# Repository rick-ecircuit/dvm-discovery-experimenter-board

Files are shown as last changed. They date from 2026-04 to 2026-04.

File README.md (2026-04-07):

# DVM Discovery Board
## Intro
The DVM Discovery Board allows students, engineers and DIYers to quickly build and learn key voltage measuring concepts and circuits. Hands-on prototyping and experimenting boosts understanding and intuition!

dvm pcb, sch

* Easy-to-use Experimenter Board.
* Circuit Options
	* 1 to 3 Customizable Voltage Ranges
	* Unipolar (+ input only) or Bipolar (+ / - input)
	* Precision Mode (Vref option)
	* Range Select: Manual Push-button or Auto 
* Simple interface to the Arduino UNO (or other MicroController).
* C Code Examples - run, modify, expand!
* Excel Design Calculator - gains, RC values, resolution, settling time.

## Flexible Hands-On Learning
* Quickly build and explore multiple measurement options. 
* Solderless headers for easy component changes.

## Building Blocks
Start with the basic circuit blocks
* Input Divider (2 Ranges)
* Low-Pass Filter
* Push-Button
Block diagram

Add blocks to expand your project
* Amplifier (additional range)
* Negative Rail (bipolar input)
* Voltage Reference (precision mode).

## Micro-Controller & C Code
* Easily interfaces to a MicroController Bd like the Arduino UNO.
* Run the code for the Basic or Advanced Voltmeter. Modify or customize for your project.
	* Basic ( 2-Range, Unipolar Input ):  DVM_discovery_basic_1.ino
	* Advanced ( 3-Range, Bipolar Input ):  DVM_discovery_3range_bipolar_1.ino

## User's Guide
* Description, Schematics, BOM
* Design and analysis equations
* DVM Examples: Basic and Advanced

## KiCAD Files
The schematic and PCB were created with KiCad, a free and open-source software suite that provides a complete EDA toolset including schematic capture, PCB layout, 3D visualization. https://www.kicad.org/

## Open-Source Project
The DVM Discovery is Open Source - anyone can inspect, make, modify and distribute the project.
Download PDFs and KiCAD PCB files (schematic, PCB, etc.).

## Excel Op Amp Design Calculator
An Excel Toolkit of Calculations created for hands-on experimenting. Apply, modify or customize as needed!
* Input Divider & Amplifier 
* Low-Pass Filter 
* Scale & Shift Network
* ADC Conversion and Resolution

<br>Let me know what you find helpful or any other comments and suggestions. Thanks!  
www.ecircuitcenter.com/contact.htm

Have fun on your next learning / design / coding adventure!

Rick  
eCircuit Center  
https://ecircuitcenter.com/

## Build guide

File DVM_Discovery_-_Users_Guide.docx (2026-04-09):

# DVM Discovery

# Hands-On & Flexible Learning of Digital Voltmeter Circuits

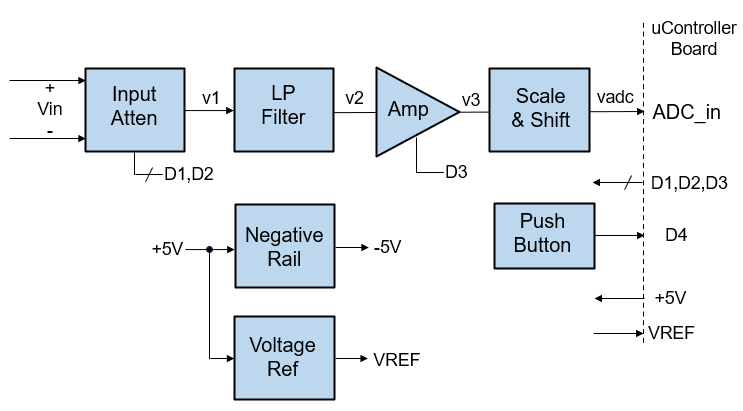
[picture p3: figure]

Contents

# 1 Intro

The DVM Discovery Board allows students, engineers and DIYers to quickly build and experiment with a variety of Digital Voltmeter Circuits. Hands-on learning of real-world circuits boosts understanding and intuition!

- Easy-to-use experimenter board
- Solderless headers allow quick component changes
- Multiple circuit design options
  - 1 to 3 Customizable Voltage Ranges
  - Unipolar (+ input only) or Bipolar (+/- input)
  - Range Select: Manual or Auto
  - Precision Mode (voltage reference option)
- Simple Interface to uController Boards (ex: Arduino UNO)
- Excel Toolkit calculates component values, ranges and resolution.

# 2 Overview

The DVM Discovery provides flexible circuitry for a multi-range voltmeter and easy uController interface. You can quickly build and explore many measurement options.

YELLOW boxes show solderless headers for easy component changes!

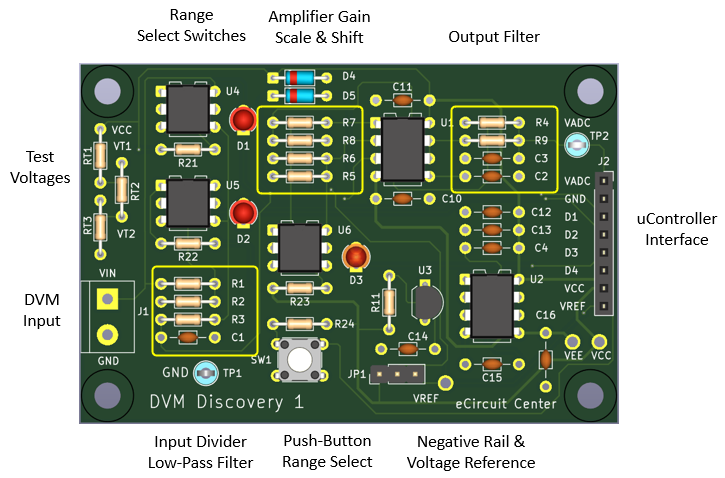
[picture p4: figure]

- Input Divider: Standard & High-Voltage Range option
- Amplifier: Low-Voltage Range option
- Negative Rail: Bipolar Input option
- Voltage Reference: Precision Mode option
- Push-Button Range Select
- LED Indicators - Digital Output Level

# 3 Applications

Here’s just a few of the real-world measurements needed across the ranges,

- 1V Range - diodes, pressure / temperature sensors, current sense voltages.
- 5V Range - 1.5V household batteries, 3.3V / 5V supplies, 4V power-tool batteries.
- 25V Range - 9V household / 12V auto batteries, 15V supplies, 18V solar cell

NOTE: You can customize the 1V / 25V ranges for your application (48V eBike batteries for example). See Make It! Section.

# 4 Block Diagram

The basic blocks allow for flexible build / design options. Customize for functionality as well as your learning goals.

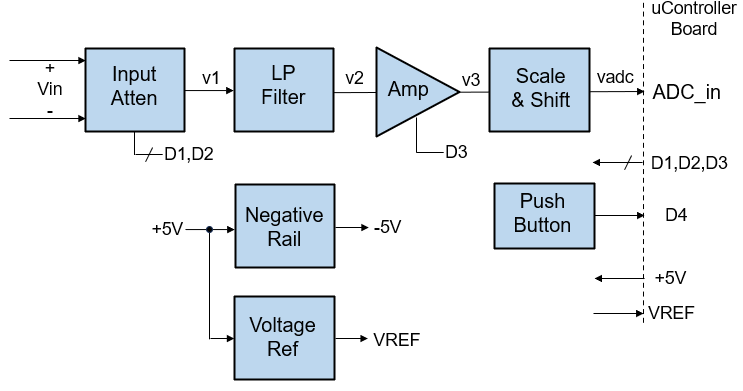
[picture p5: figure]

# 5 Simplified Signal Flow

The simplified diagram below shows the main path of the measured signal.

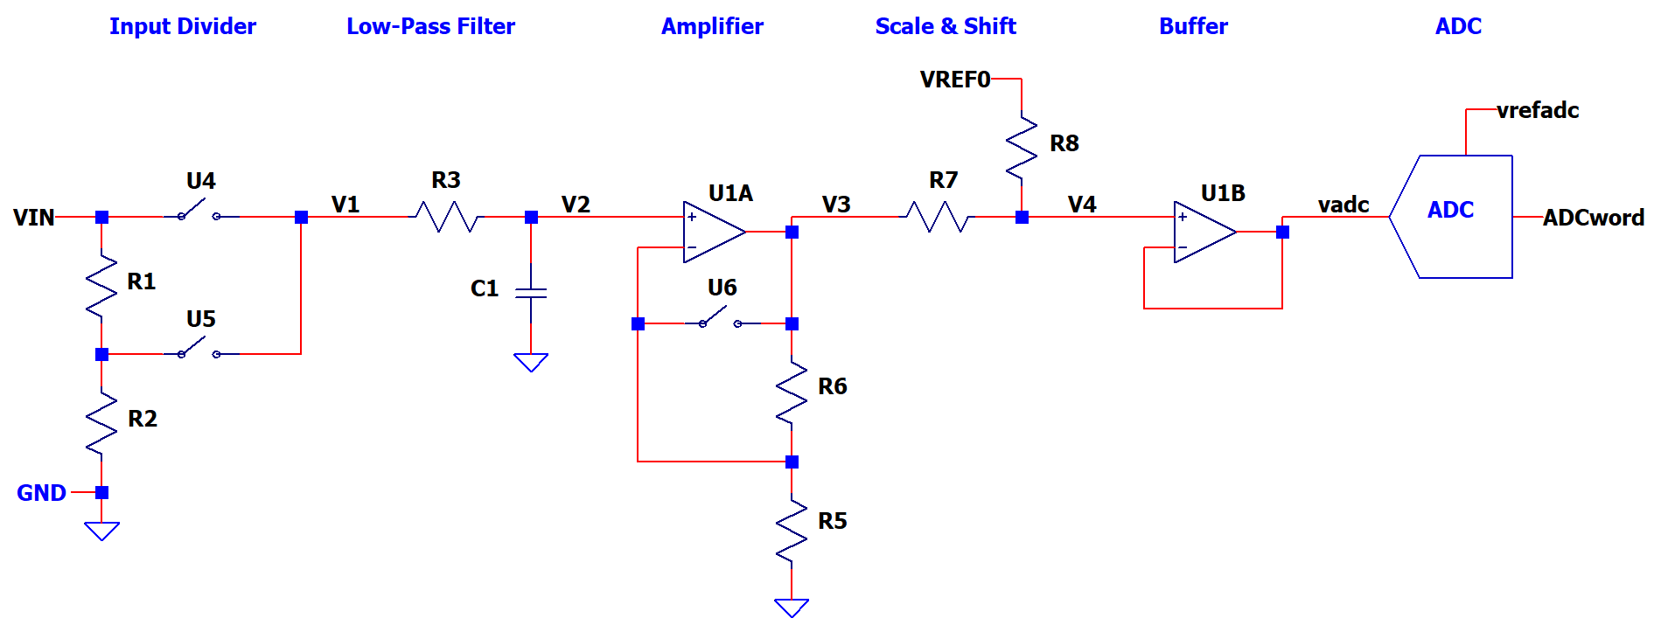
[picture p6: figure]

# 6 Gain Stages vs Ranges

How can you achieve three voltage ranges? The RED shading shows CLOSED switches.

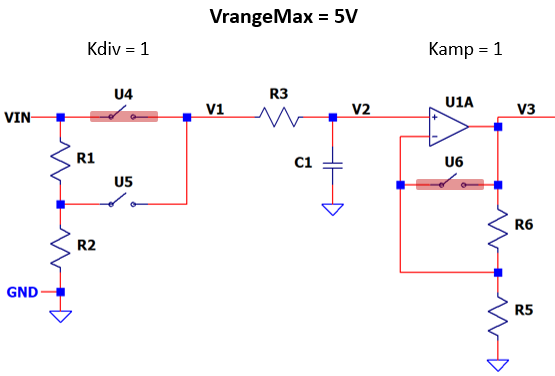
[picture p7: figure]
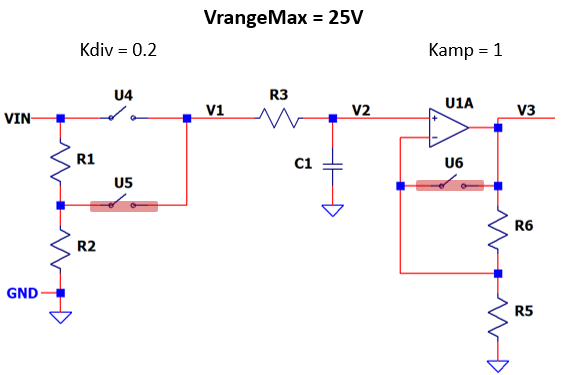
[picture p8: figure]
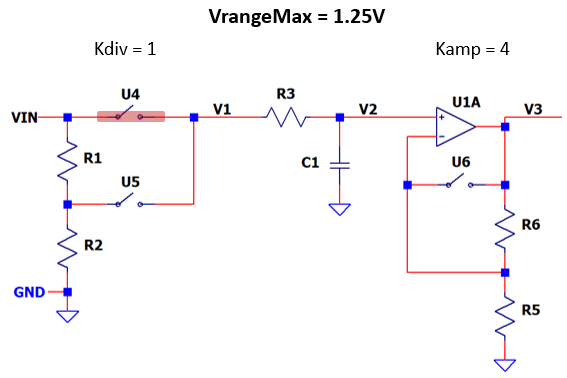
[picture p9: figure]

# 7 Schematic

The DVM Discovery is created using straightforward circuits and standard parts. They provide practical real-world applications of classic circuits. You can also deep dive into the theory of these foundational circuits as well.

NOTE: For full schematic, see Bonus Sections.

## 7.1 Input Divider, Analog Mux, Low-Pass Filter

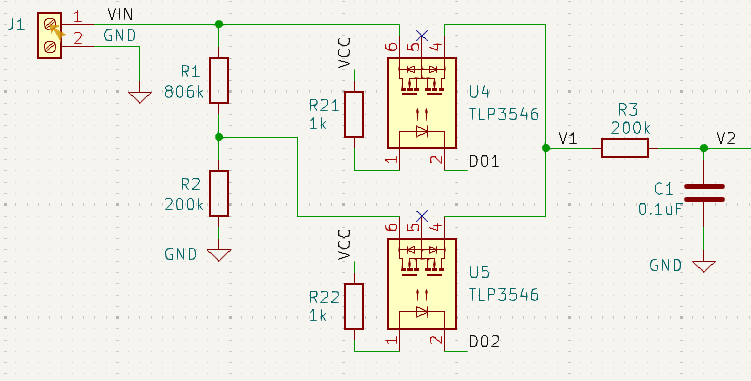
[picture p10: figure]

Input Voltage Divider

- The R1, R2 Divider scales down high voltages to the +5V max of the ADC input. Kdiv = V1 / Vin = R2 / (R1+R2)

Analog Mux

- Solid-State Relays U4 and U5 create an Analog Mux
  - Normal Voltage Range: U4 connects Vin directly to V1.
  - High Voltage Range: U5 connects the Divider tap to V1.

Low-Pass Filter

- R3, C1 create a low-pass filter: fc = 1 / (2 * pi* R3 * C1)
- Reduces unwanted 60Hz, radio interference and protects against input spikes.

## 7.2 Amplifier with Selectable Gain

You can configure U1 as a selectable gain amplifier or a unity-gain buffer.

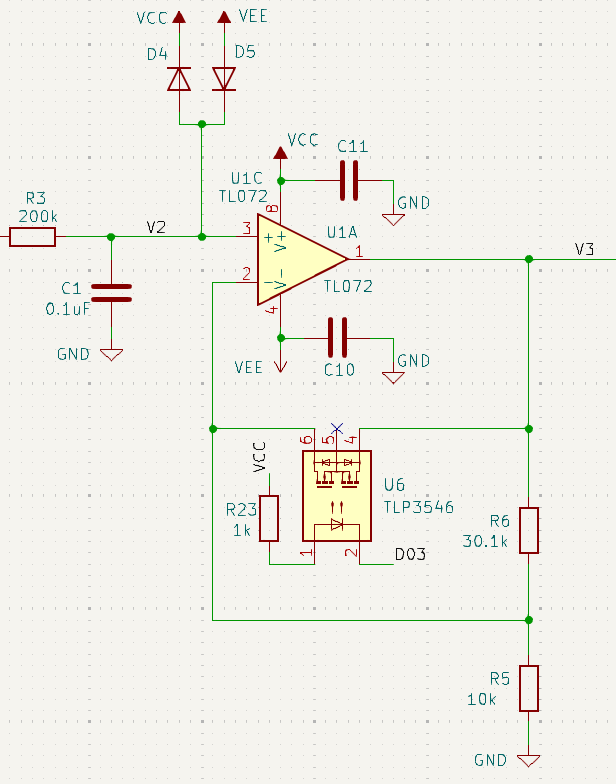
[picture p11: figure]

Selectable Gain Amplifier

- Unity Gain Amplifier - U6 Switch ON
  - U6 shorts U1 output to negative input.
- Gain Amplifier - U6 Switch OFF
  - Ka = V3 / V2 = R6 / R5 + 1

Unity-Gain Amplifier

- U6 not used.
- R5 = short (or < 100 ohms)
- R6 = open

Input Protection

- Schottky Diodes D4, D5 limit V2 to within VCC and VEE keeping U1’s pins under their MAX voltage input rating.

## 7.3 Scale & Shift, Buffer

You can scale and shift a bipolar input (-5V to 5V) to a unipolar one (0V to 5V) using a simple two resistor network R7, R8!

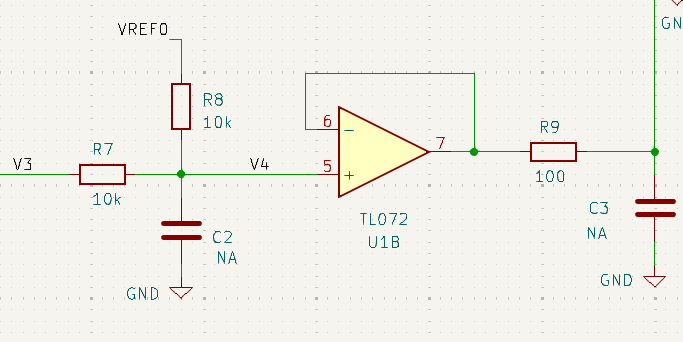
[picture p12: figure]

Scale and Shift

Kscale=(V4)/(V3)=(R8)/(R7+R8)

Voffset=VREF0∙(R7)/(R7+R8)

Unipolar Input Mode – No Scale or Shift

- Input: V3 = 0 to 5V Range
- Output: V4 = 0 to 5V Range
  - R7 = 1k, R8 = open
  - Scale: Kscale = 1 (Unity Gain)
  - Shift: Voffset = 0V

Bipolar Input Mode - Scale & Shift

- Input: V3 = -5V to 5V Range
- Output: V4 = 0 to +5V Range
  - R7 = 10k, R8 = 10k, VREF0 = +5.0V
  - Scale: Kscale = R8 / (R7+R8) = 0.5
  - Shift: Voffset = Vref0 * R7 / (R7+R8) = +2.5V
  - V4 = V3*0.5 + 2.5V

Optional Low-Pass Filters

- R7||R8 and C2: fc = 1 / (2 * π * R7||R8 * C2)
- R9 and C3: fc = 1 / (2 * π * R10 * C3)

## 7.4 Buffer and External Interface

Output Buffer

- U1B buffers the medium impedance at node V4 and drives the Microcontroller’s ADC input.
- R9 can provide isolation from capacitive load if driving long cables / wires to ADC input.
- C3 (and R9) can provide addition low-pass filtering.

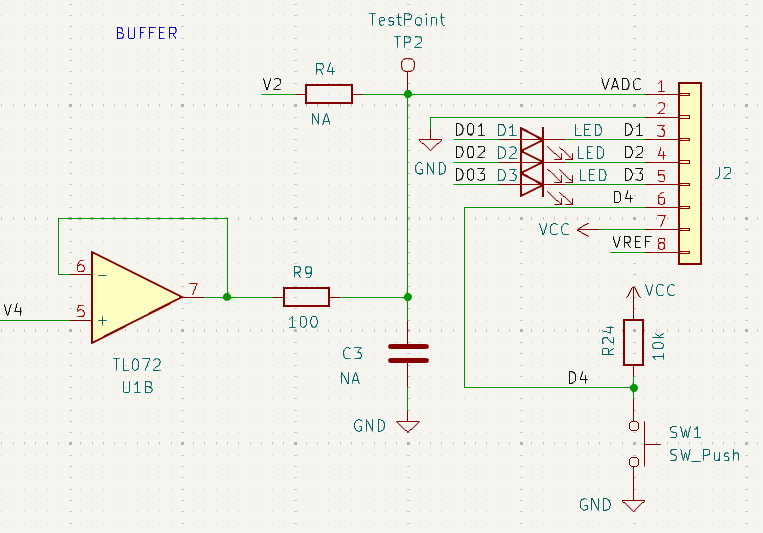
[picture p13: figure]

Microcontroller Interface

- Connector J2 allows easy access to external controller or computer.

Signals | Controller Signal | Description
VCC, GND | Power | Power for DVM PCB
D1, D2, D3 | Digital Outputs | Solid-State Switch Control Low State – Turns ON U4, U5, U6
D4 | Digital Input | Push-Button State for Range Select.
ADC | Analog Input A0 | Voltmeter Reading
VREF | Analog Input (A1) | Reference Voltage for Precision Mode

Pushbutton

- SW1 for external input to manually select Vrange.

LED Indicators - Digital LO & Switch ON

- LEDs (D1,D2,D3) light up when digital outputs (D1,D2,D3) are driven LO turning Opto-Switches (U4,U5,U6) ON.

## 7.5 Negative Rail

You’ll need a negative supply to power U1 for bipolar inputs.

- U2 is a Switched-Capacitor Converter that creates a negative voltage (VEE) from a positive input voltage (VCC).
- U2’s internal switches alternatively charge C15 to VCC then deliver the charge to C16.

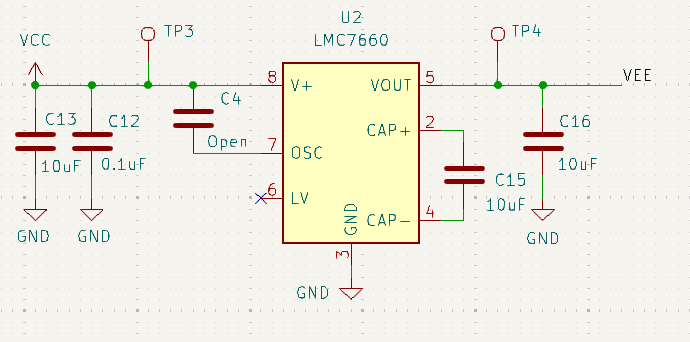
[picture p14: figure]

## 7.6 Voltage Reference

A precise voltage reference enables you to measure in Precision Mode.

- U7 is an IC that behaves like a precision 2-terminal Zener Diode.

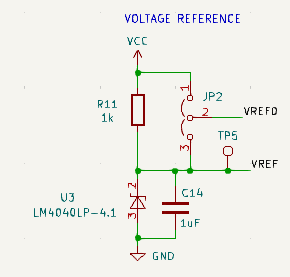
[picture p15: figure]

- VREF0 drives the Scale and Shift Network
  - VREF0 = VCC = +5V (JP1: 1-2)
  - VREF0 = VREF = +4.096V (JP1: 2-3)

Precision Mode Options

1. Connect VREF to an ADC input. You can measure this precision voltage and apply a Gain correction to all VIN readings.
2. Connect VREF directly to the Vref pin of the controller’s ADC. The ADC automatically scales the measurements to this reference.

## 7.7 Input Test Levels

A simple resistor string provides 3 handy on-board voltages for testing multiple ranges. For RT1 = RT2 = 10k and RT3 = 1k you get the following levels.

- VCC = +5V Supply.
- VT1 = VCC * (RT2+RT3) / (RT1+RT2+RT3) = 2.619V
- VT2 = VCC * (RT3) / (RT1+RT2+RT3) = 0.238V

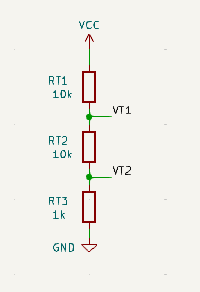
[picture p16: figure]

Create any two test voltages that you might need!

# 8 Voltage Range Setup

## 8.1 Ranges (Default)

Range | Vrange | Vrange Max | Overrange (%)
Standard | 4V | 5V | 25%
High | 20V | 25V | 25%
Low | 1V | 1.25V | 25%

## 8.2 Voltage Range, Gains and Digital Outputs

Voltage Range | Divider Gain | Amplifier Gain | Analog Switches | Digital Outputs
Standard | 1.0 | 1.0 | U4 = ON U6 = ON | D1 = LO D3 = LO
High | R2 / (R1+R2) | 1.0 | U5 = ON U6 = ON | D2 = LO D3 = LO
Low | 1.0 | R6 / R5 + 1 | U4 = ON | D1 = LO

NOTE: LED’s D1, D2, D3 turn ON when digital outputs D1, D2, D3 go LO!

## 8.3 Signal Levels

Polarity | VIN | V4 | VADC
Unipolar | 0V to +Vrange_max | 0V to +5V | 0V to +5V 0V at VIN = 0
Bipolar | -Vrange_max to +Vrange_max | -5V to +5V | 0V to +5V 2.5V at VIN = 0

## 8.4 Software Calculation of VIN

Polarity | VIN | Ktot | Calc VIN from ADCword
Unipolar | 0 to +Vrange_max | Kdiv*Kamp | VIN = (ADCword / 1024 * VREF) / Ktot
Bipolar | -Vrange_min to +Vrange_max | Kdiv*Kamp*Kscale | VIN = (ADCword / 1024 * VREF – VREF / 2) / Ktot

# 9 DVM Basic - 2 Ranges, Unipolar Input

Let’s take our DVM for a test drive! Build this voltmeter to get some hands-on experience with multi-ranges. You’ll get to apply some real-world testing of your house-hold batteries.

Description

- Ranges: +4V, +20V
- Input: Unipolar (Pos input only)
- Range Select: Manual Push-Button
- Low-Pass Filter: 8 Hz
- Overrange: +5V, +25V (25%)

Simplified Schematic

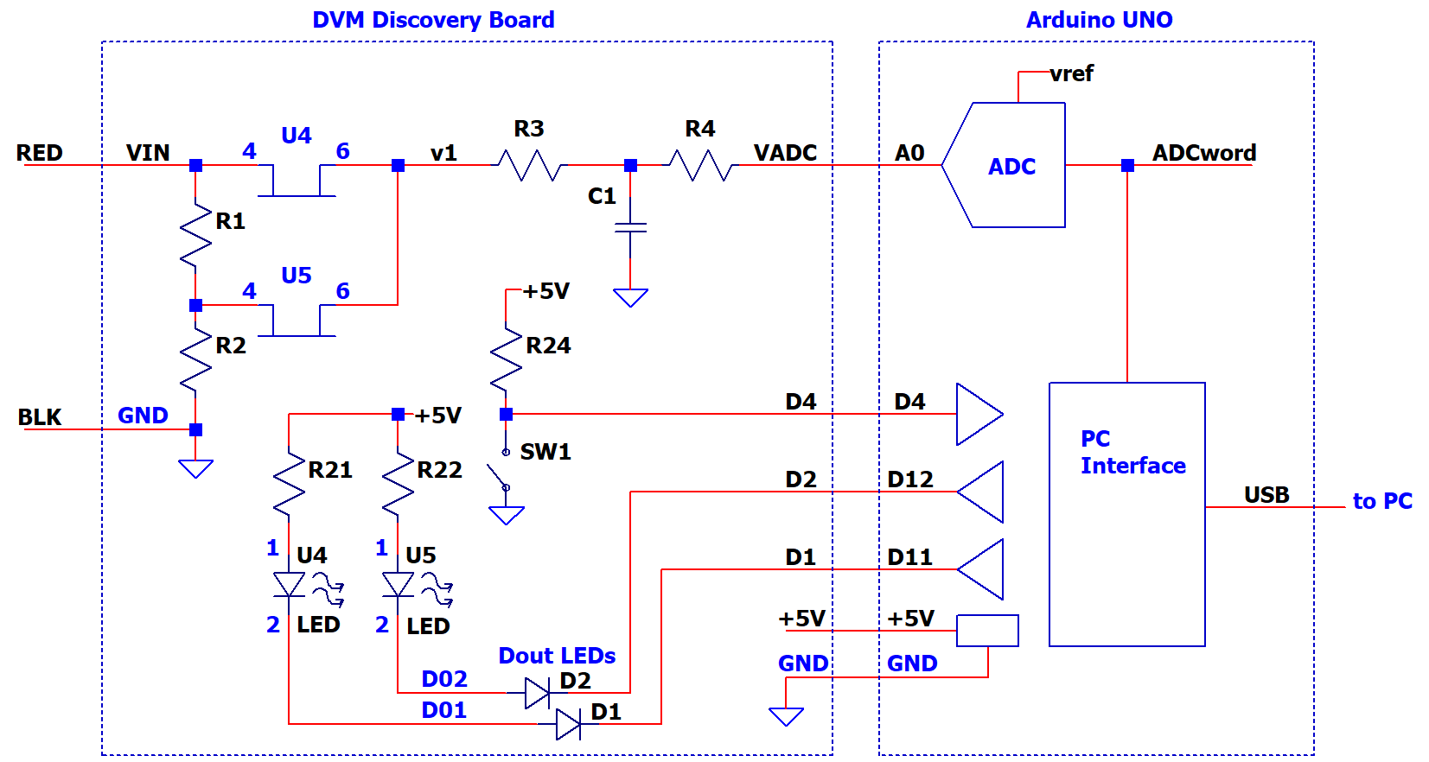
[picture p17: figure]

Install Components on PCB (See DVM Basic in Make it! Section)

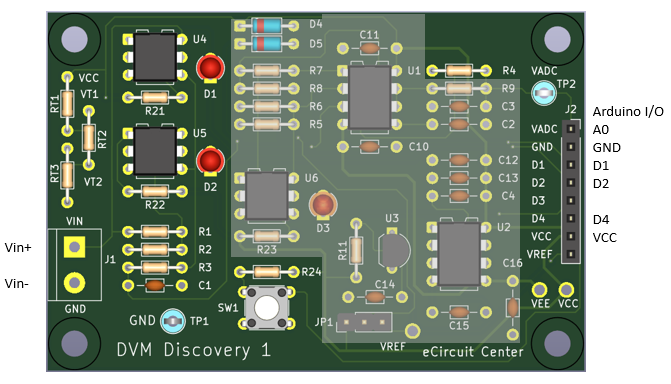
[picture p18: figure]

Install Components on 4-Pin Solderless Headers

- R1 = 825k, R2 = 200k (Input Divider)
- R3 = 200k, C1 = 0.1uF (Low-Pass Filter)
- R4 = 1k (connect to VADC)

Option: Solder components above directly on PCB without headers.

Connect Arduino UNO to DVM Discovery

Arduino | Description | Discovery | Description
A0 | Analog ADC Input | VADC | Measured Voltage Signal
D11, D12 | Digital Outputs | D1, D2 | Opto-Switch Control and LEDs
D4 | Digital Input | D4 | Push-Button Logic State
+5V, GND | Power | VCC, GND | Power for Switches, Amp, etc.

Check Out

- Connect Arduino USB to PC or Laptop
- Use a DVM to verify +5.0V between Testpoints VCC and GND.

Run Code

- Download the file: DVM_discovery_basic_1.ino
- Start the Arduino IDE and Open the file listed above.
- Hit the Upload and Run buttons.
- Press pushbutton repeatedly and verify that LEDs D1 and D2 alternately turn ON and OFF.

Test Voltage

- Press the push-button to select the 4V Range. LEDs: D1 = ON, D2 = OFF
- Connect the VIN Test Clip (RED) to VT1 (2.69V).
- Read voltage at Arduino Serial Monitor on the PC screen.
- Very the reading is within +/-0.05V
- Press the push button to select the 20V Range. LEDs: D1 = OFF, D2 = ON
- Read voltage.
- Very the reading is within +/-0.1V

Test 1.5V and 9V Batteries

- Connect a 1.5V or 9V battery’s + and -leads to VIN and GND.
- Select the 4V or 20V Range.
- Check 1.5V health - between 1.1V and 1.5V
- Check 9V health - between 7.5V and 9V.

# 10 DVM Advanced - 3 Ranges, Bipolar Input

Let’s extend the capabilities of our DVM to 3 Voltage Ranges and measure both
+/- input polarities!

Description

- Ranges: ±1V, ±4V, ±20V
- Input: Bipolar (Pos & Neg Voltages)
- Range Select: Manual Push-Button
- Low-Pass Filter: 8 Hz
- Overrange: ±1.25V, ±5V, ±25V (25%)

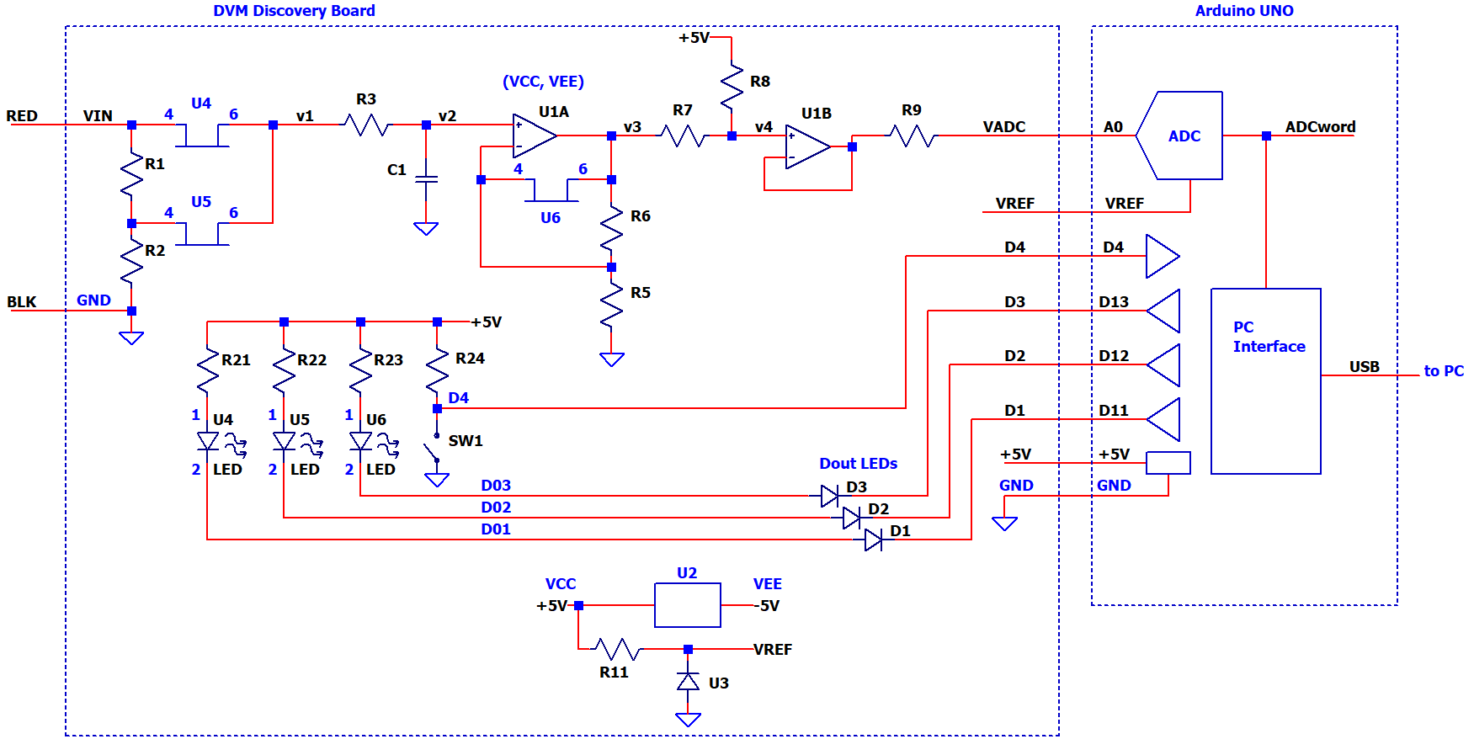
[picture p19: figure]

Simplified Schematic

Install Components on PCB (See DVM Advanced in Make it! Section)

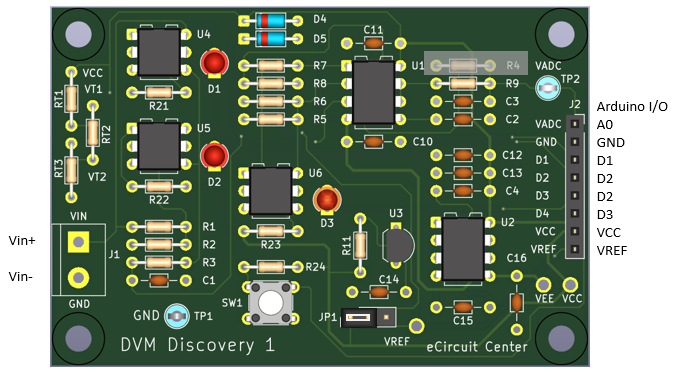
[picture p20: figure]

Install Components on 4-Pin Solderless Headers

- R1 = 825k, R2 = 200k (Input Divider)
- R3 = 200k, C1 = 0.1uF (Low-Pass Filter)
- R5 = 10k, R6 = 30.1k (Amplifier)
- R7 = 10k, R8 = 10k (Scale and Shift)
- R9 = 1k (connect to VADC)

Option: Solder components above directly on PCB without headers!

Jumpers

- JP1:1-2 (VREF0 = +5V)

Connect Arduino UNO to DVM Discovery

Arduino | Description | Discovery | Description
A0 | Analog ADC Input | VADC | Measured Voltage Signal
D11, D12, D13 | Digital Outputs | D1, D2, D3 | Opto-Switch Control and LEDs
D4 | Digital Input | D4 | Push-Button Logic State
+5V, GND | Power | VCC, GND | Power for Switches, Amp, etc.

Check Out

- Connect Arduino USB to PC or Laptop
- Use a DVM to verify +5.0V between Testpoints VCC and GND.
- Verify -5.0V between VEE and GND.
- Verify +4.906V between VREF and GND.

Run Code

- Download the file: DVM_discovery_3range_bipolar_1.ino
- Start the Arduino IDE and Open the file listed above.
- Hit the Upload and Run button.
- Press pushbutton repeatedly and verify that LEDs D1, D2, D2 turn ON and OFF.

4V Range

- Press the push-button to select the 4V Range. LEDs: D1 = ON, D2 = OFF, D3 = ON
- Connect the VIN Test Clip (RED) to VT1 (2.619V).
- Read voltage at Arduino Serial Monitor on the PC screen.
- Verify the reading is within +/-0.05V

20V Range

- Press the push button to select the 20V Range. LEDs: D1 = OFF, D2 = ON, D3 = ON
- Connect the VIN Test Clip (RED) to VT1 (2.619V).
- Verify the reading is within +/-0.1V

1V Range

- Press the push button to select the 1V Range. LEDs: D1 = ON, D2 = OFF, D3 = OFF
- Connect the VIN Test Clip (RED) to VT2 (0.238V).
- Verify the reading is within +/-0.05V

# 11 Make it!

Here’s the parts list for the Basic and Advanced DVMs.

- Modify and build for your own learning goals.
- Install only parts needed for your design.
- All Resistors: 1/4W, 5% unless noted.
- All Capacitors: Ceramic, >25V

You can customize the high and low ranges for your application.

- High Range (25V default) – adjust R1, R2
- Low Range (1V default) – adjust R6, R5

## 11.1 DVM Basic - 2 Ranges, Unipolar Input

PASSIVES

R1 | 1 | 825k | 1% for precision | Install group on 4-pin headers
R2 | 1 | 200k | 1% for precision
R3 | 1 | 200k
C1 | 1 | 0.1uF
R4 | 1 | 1k | | Install group on 4-pin headers
R9 | 1 | Open
C3 | 1 | Open | | Optional low-pass filtering
C2 | 1 | Open | | Optional low-pass filtering
R21, R22 | 2 | 1k
RT1, RT2 | 2 | 10k
RT3 | 1 | 1k
D4, D5 | 2 | Diode | 1N5711
D1, D2 | 2 | LED Yel | LTL-4253 | Any color you prefer.

INTEGRATED CIRCUITS

U4, U5 | 2 | Opto-Isolated Solid-State Switch | TLP592 type or equivalent | Ron < 10 ohms

HARDWARE

R1 - C1 R4 - C3 | 4 | 4-pin Socket Header for components | SSW-104-01-T-S | Install on both sides of component groups.
U4, U5 | 4 | 3-pin female break-away socket strip | | Install on both sides for opto switches.
J2 | 1 | 8-pin Socket Header | SSW-108-01-T-S
J1 | 1 | 2-pin Terminal Block screw type | | Optional: Solder test leads (spring or alligator clips) directly to J1 pads.
TP1 | 1 | TestPoint | 5011

## 11.2 DVM Advanced - 3 Ranges, Bipolar Input

PASSIVES

C10, C11, C12 | 3 | 0.1uF | | All caps Ceramic, >25V
C13, C14, C15, C16 | 2 | 10uF
R1 | 1 | 825k | 1% for precision | Install group on 4-pin headers
R2 | 1 | 200k | 1% for precision
R3 | 1 | 200k
C1 | 1 | 0.1uF
R5 | 1 | 10k | 1% for precision | Install group on 4-pin headers
R6 | 1 | 30.1k | 1% for precision
R7 | 1 | 10k | 1% for precision
R8 | 1 | 10k | 1% for precision
R4 | 1 | Open | | Install group on 4-pin headers
R9 | 1 | 1k
C3 | 1 | Open | | Optional low-pass filtering
C2 | 1 | Open | | Optional low-pass filtering
R11, R21, R22, R23 | 4 | 1k
RT1, RT2 | 2 | 10k
RT3 | 1 | 1k
D4, D5 | 3 | Diode | 1N5711
D1, D2, D3 | 3 | LED Yel | LTL-4253 | Any color you prefer.

INTEGRATED CIRCUITS

U1 | 1 | Op Amp | LMC6082IN/NOP8 | Dual op amp, rail-to-rail output, +/-7.5V supply max, DIP
U2 | 1 | Negative Rail Charge Pump | AD7660NP
U3 | 1 | Voltage Reference Shunt | LM4040xx
U4, U5, U6 | 3 | Opto-Isolated Solid-State Switch | TLP592 type or equivalent | Ron < 10 ohms

HARDWARE

R1 - C1 R5 - R8 R4 - C3 | 6 | 4-pin Socket Header for components | SSW-104-01-T-S | Install on both sides of component groups.
U1, U2 | 2 | DIP-8 Socket | 4808-3000-CP
U4, U5, U6 | 6 | 3-pin female break-away socket strip | | Install both sides for opto switches.
J2 | 1 | 8-pin Socket Header | SSW-108-01-T-S
J1 | 1 | 2-pin Terminal Block screw type | | Optional: Solder test leads (spring or alligator clips) directly to J1 pads.
JP1 | 1 | 3-pin Header | TSW-103-08-T-S | 1 Shunts needed SNT-100-BK-T
TP1 | 1 | TestPoint | 5011

# 12 Bonus Sections

## 12.1 Revision & Notes

DVM Discovery User’s Guide: Rev 1a

The DVM Discovery provides real-world hands-on experiences to developing skills, understanding and intuition about measurement topologies.

Rick Faehnrich

https://www.linkedin.com/in/rick-faehnrich-2671a911/

## 12.2 Learning Styles

Dive in any way that propels your learning with Self-Directed or Guided Learning (or a combination of both).

- Self-Directed Learning - Explore circuits entirely on your own.
- Guided Examples – Follow a walk-through of two DVM implementations:
  - 2-Range, Unipolar Input
  - 3 Range, Bipolar Input
- Mixed Mode - Get ideas from the Guided examples and follow-through on your own.

## 12.3 Arduino Software

Here's the fast track steps of running a C program (sketch) on your Arduino Board.

- Download and install the Arduino IDE Software. https://www.arduino.cc/en/software
- Connect UNO Board to your computer https://docs.arduino.cc/hardware/uno-rev3/
- Open the Arduino IDE Software.
- Select Board Name Select UNO from drop down menu.
- Copy the program (sketch) to your Arduino folder and Open it. DVM_discovery_basic_1.ino
- Click Compile Button Generates executable code, checks for errors.
- Click the Upload Button Uploads compiled code into UNO and begins running.
- Click the Serial Monitor Window displays output from PrintSerial statement.

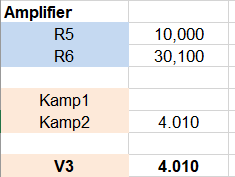
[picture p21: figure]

## 12.4 Excel DVM Design Calculator

A handy Design and Analysis Toolkit.
https://ecircuitcenter.com/DVM1/dvm-discovery.html

1. Calculate gains, signal levels and ADC digital values.
2. Modify, customize for your own projects.

## 12.5 KiCAD Software

KiCad is a free and open-source software suite that provides a complete EDA toolset including schematic capture, PCB layout, 3D visualization, and circuit simulation. https://www.kicad.org/

## 12.6 GitHub

The DVM Discovery Bd is an open-source project intended to make op amp learning as accessible and affordable as possible. You can download the documentation and KiCAD project files at https://github.com/rick-ecircuit.

## 12.7 Feedback eCircuitCenter

Feedback on eCircuit Center

- How is the DVM Discovery Bd helpful for you?
- What needs clarity?
- Other comments, suggestions?

Send your thoughts on the feedback form at eCircuit Center.
https://ecircuitcenter.com/contact.htm

eCircuit Center strives to provide informal, hands-on and fun experiences that lead to a deeper, more intuitive understanding of circuit design and analysis.

## 12.8 The Power of Play

- Key to analog success: play, play, play with circuits!
- Analog circuits appear more inviting (and less intimidating) when playing and tinkering.
- Learning and passion grow when you
  - Ask “what if” questions
  - Play with component values - Predict the outcome!
  - Small discoveries and learning fuel motivation and the joy of learning.

## 12.9 KiCAD Schematic

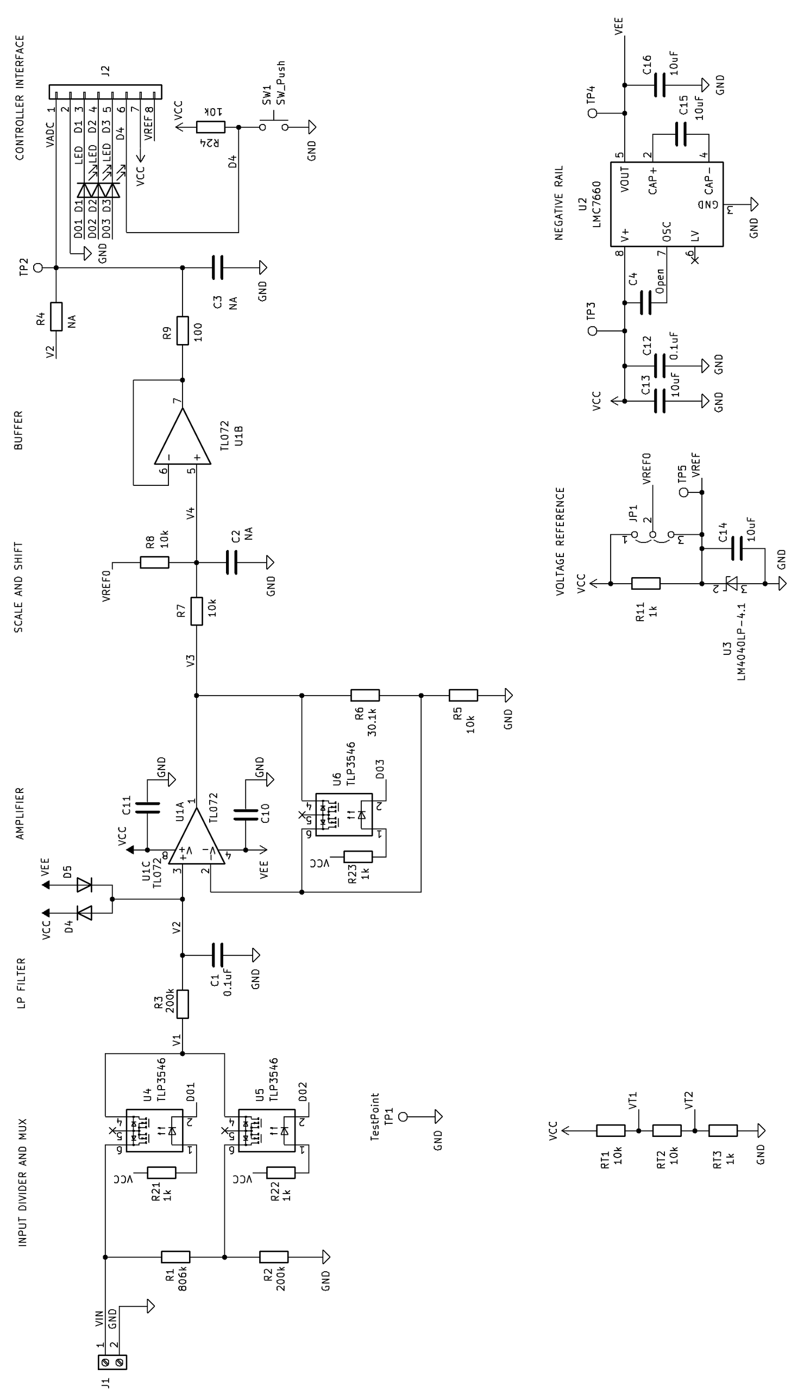
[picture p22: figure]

2 eCircuit Center Rev 1a

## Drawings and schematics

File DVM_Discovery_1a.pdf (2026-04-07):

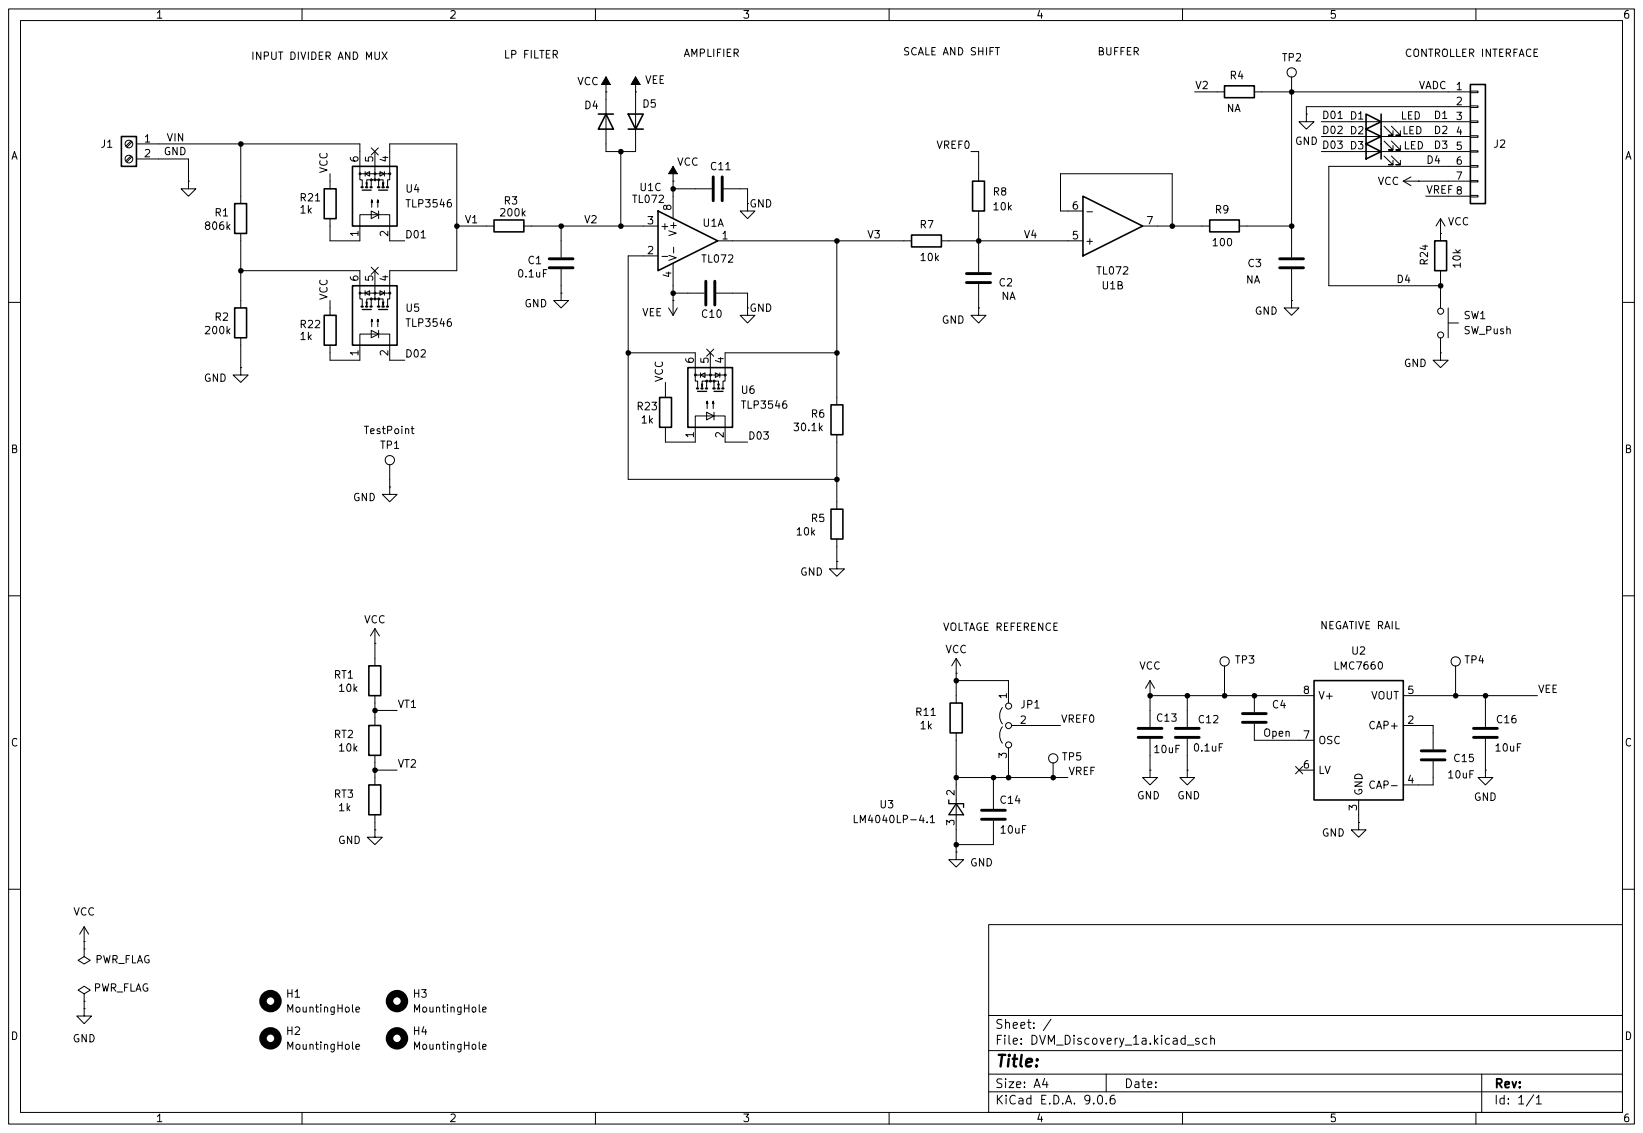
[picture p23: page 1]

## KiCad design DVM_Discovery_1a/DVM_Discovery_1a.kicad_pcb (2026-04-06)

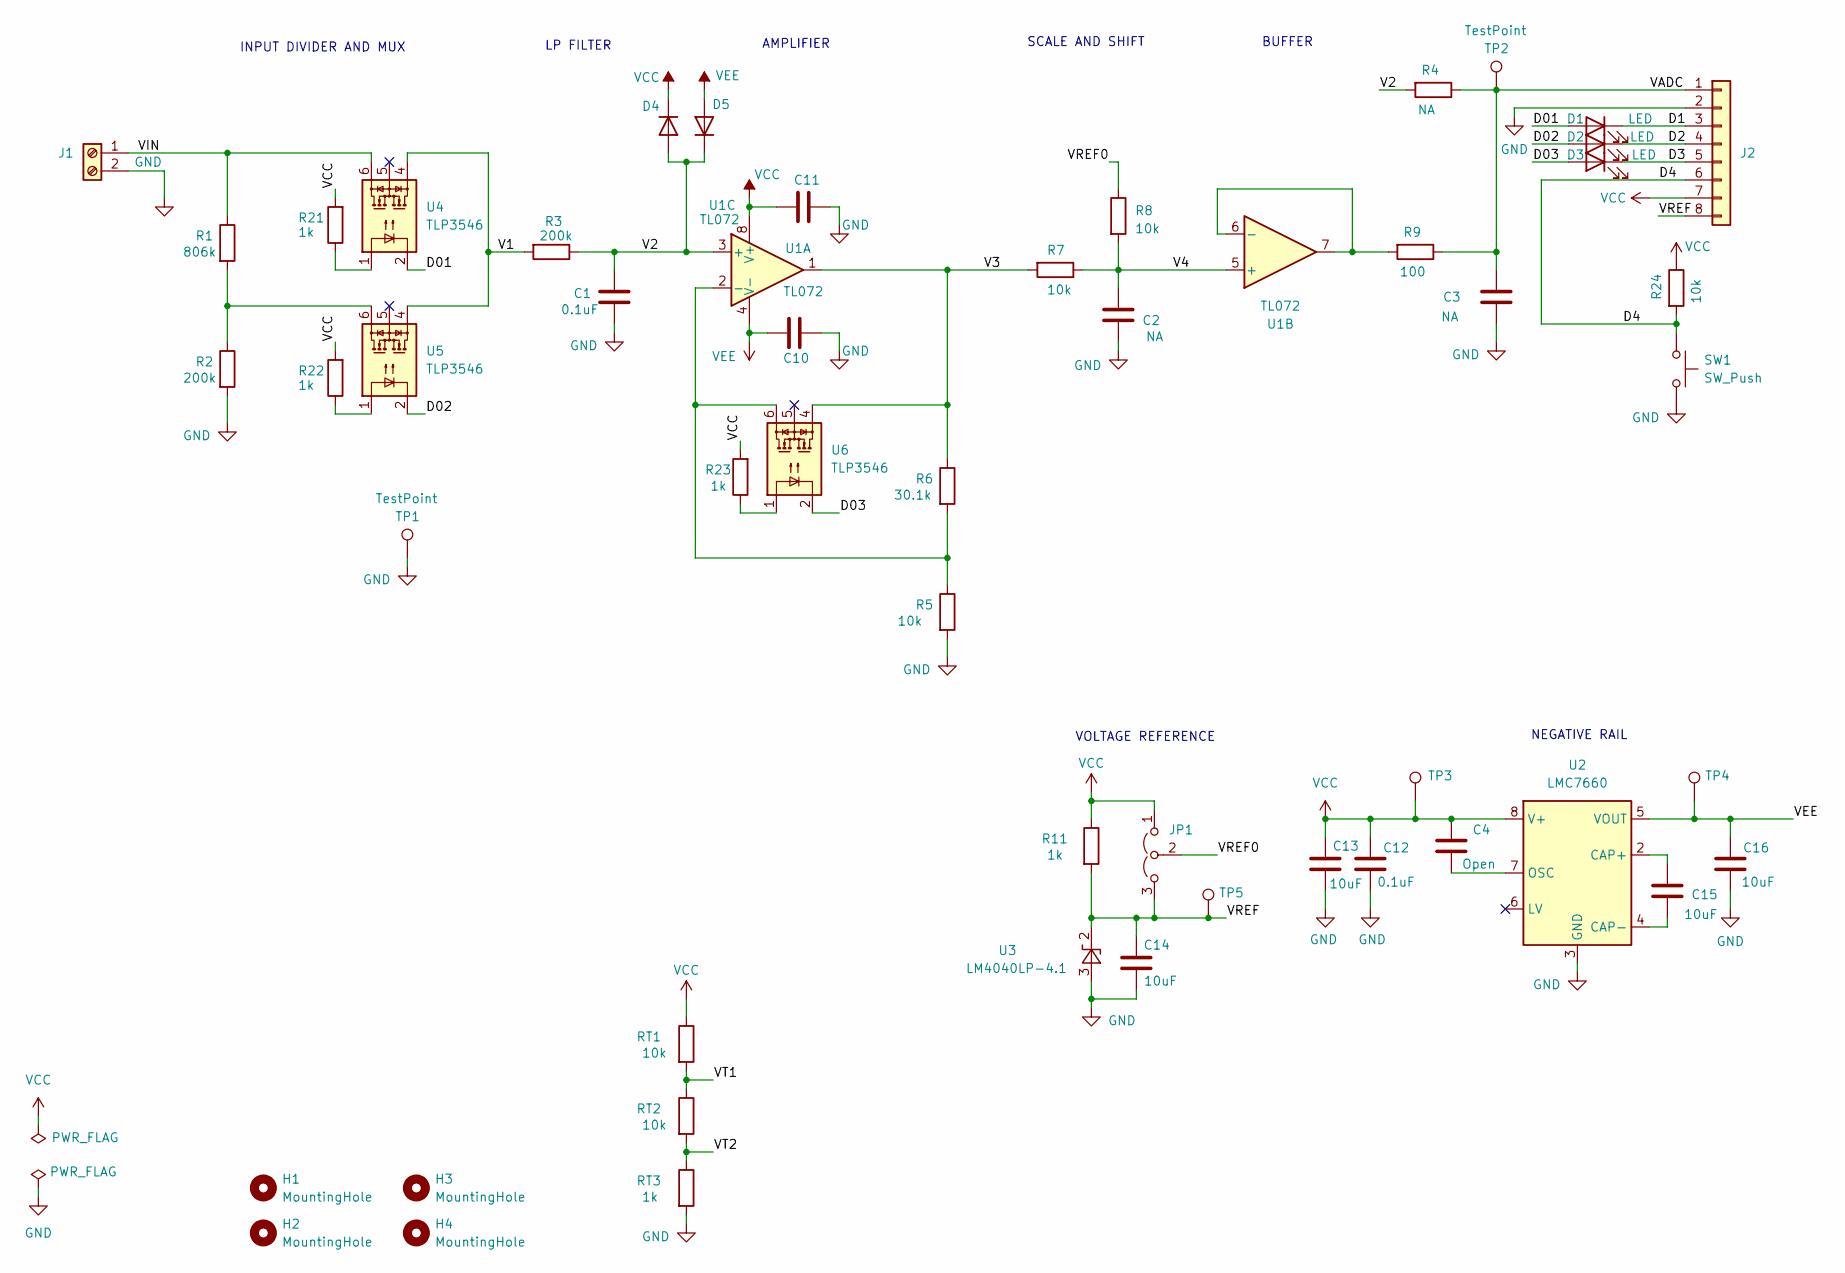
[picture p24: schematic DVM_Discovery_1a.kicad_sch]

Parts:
C1, C10, C11, C12: 0.1uF; C_Disc_D3.0mm_W1.6mm_P2.50mm_wider_center_dia
C2, C3: NA; C_Disc_D3.0mm_W1.6mm_P2.50mm_wider_center_dia
C4: Open; C_Disc_D3.0mm_W1.6mm_P2.50mm_wider_center_dia
C13, C14, C15, C16: 10uF; C_Disc_D3.0mm_W1.6mm_P2.50mm_wider_center_dia
D1, D2, D3: LED; LED_D3.0mm
D4, D5: 1N914; D_DO-35_SOD27_P7.62mm_Horizontal
H1, H2, H3, H4: MountingHole; MountingHole_3.7mm
J1: Screw_Terminal_01x02; TerminalBlock_bornier-2_P5.08mm
J2: Conn_01x08; PinSocket_1x08_P2.54mm_Vertical
JP1: Jumper_3_Open; PinHeader_1x03_P2.54mm_Vertical
R1: 806k; R_Axial_DIN0204_L3.6mm_D1.6mm_P7.62mm_Horizontal-bigger_hole
R2, R3: 200k; R_Axial_DIN0204_L3.6mm_D1.6mm_P7.62mm_Horizontal-bigger_hole
R4: NA; R_Axial_DIN0204_L3.6mm_D1.6mm_P7.62mm_Horizontal-bigger_hole
R5, R7, R8, R24: 10k; R_Axial_DIN0204_L3.6mm_D1.6mm_P7.62mm_Horizontal-bigger_hole
R6: 30.1k; R_Axial_DIN0204_L3.6mm_D1.6mm_P7.62mm_Horizontal-bigger_hole
R9: 100; R_Axial_DIN0204_L3.6mm_D1.6mm_P7.62mm_Horizontal-bigger_hole
R11, R21, R22, R23: 1k; R_Axial_DIN0204_L3.6mm_D1.6mm_P7.62mm_Horizontal-bigger_hole
RT1, RT2: 10k; R_Axial_DIN0204_L3.6mm_D1.6mm_P7.62mm_Horizontal-bigger_hole
RT3: 1k; R_Axial_DIN0204_L3.6mm_D1.6mm_P7.62mm_Horizontal-bigger_hole
SW1: SW_Push; SW_TH_Tactile_Omron_B3F-100x
TP1, TP2: TestPoint; TestPoint_Keystone_5005-5009_Compact
TP3, TP4, TP5: TestPoint; TestPoint_THTPad_D2.0mm_Drill1.0mm_bigger
U1: TL072; DIP-8_W7.62mm
U2: LMC7660; DIP-8_W7.62mm
U3: LM4040LP-4.1; TO-92_Inline_Wide
U4, U5, U6: TLP3546; DIP-6_W7.62mm

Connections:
/D1: D1.1 (K), J2.3
/D01: D1.2 (A), U4.2
/D2: D2.1 (K), J2.4
/D02: D2.2 (A), U5.2
/D3: D3.1 (K), J2.5
/D03: D3.2 (A), U6.2
/D4: J2.6, R24.2, SW1.1
/V1: R3.2, U4.4, U5.4
/V2: C1.1, D4.2 (A), D5.1 (K), R3.1, R4.2, U1.3 (+)
/V3: R6.1, R7.2, U1.1, U6.4
/V4: C2.1, R7.1, R8.2, U1.5 (+)
/VADC: C3.1, J2.1, R4.1, R9.1, TP2.1
/VIN: J1.1, R1.1, U4.6
/VREF: C14.1, J2.8, JP1.3 (B), R11.2, TP5.1, U3.2 (K)
/VREF0: JP1.2 (C), R8.1
/VT1: RT1.2, RT2.1
/VT2: RT2.2, RT3.1
GND: C1.2, C2.2, C3.2, C10.2, C11.2, C12.2, C13.2, C14.2, C16.2, J1.2, J2.2, R2.2, R5.2, RT3.2, SW1.2, TP1.1, U2.3 (GND), U3.3 (A)
unnamed: R1.2, R2.1, U5.6
unnamed: R21.1, U4.1
unnamed: R22.1, U5.1
unnamed: R23.1, U6.1
unnamed: R5.1, R6.2, U1.2 (-), U6.6
unnamed: R9.2, U1.6 (-), U1.7
unnamed: C15.1, U2.2 (CAP+)
unnamed: C15.2, U2.4 (CAP-)
unnamed: C4.2, U2.7 (OSC)
VCC: C4.1, C11.1, C12.1, C13.1, D4.1 (K), J2.7, JP1.1 (A), R11.1, R21.2, R22.2, R23.2, R24.1, RT1.1, TP3.1, U1.8 (V+), U2.8 (V+)
VEE: C10.1, C16.1, D5.2 (A), TP4.1, U1.4 (V-), U2.5 (VOUT)

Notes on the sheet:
LP FILTER
AMPLIFIER
BUFFER
SCALE AND SHIFT
NEGATIVE RAIL
INPUT DIVIDER AND MUX
VOLTAGE REFERENCE

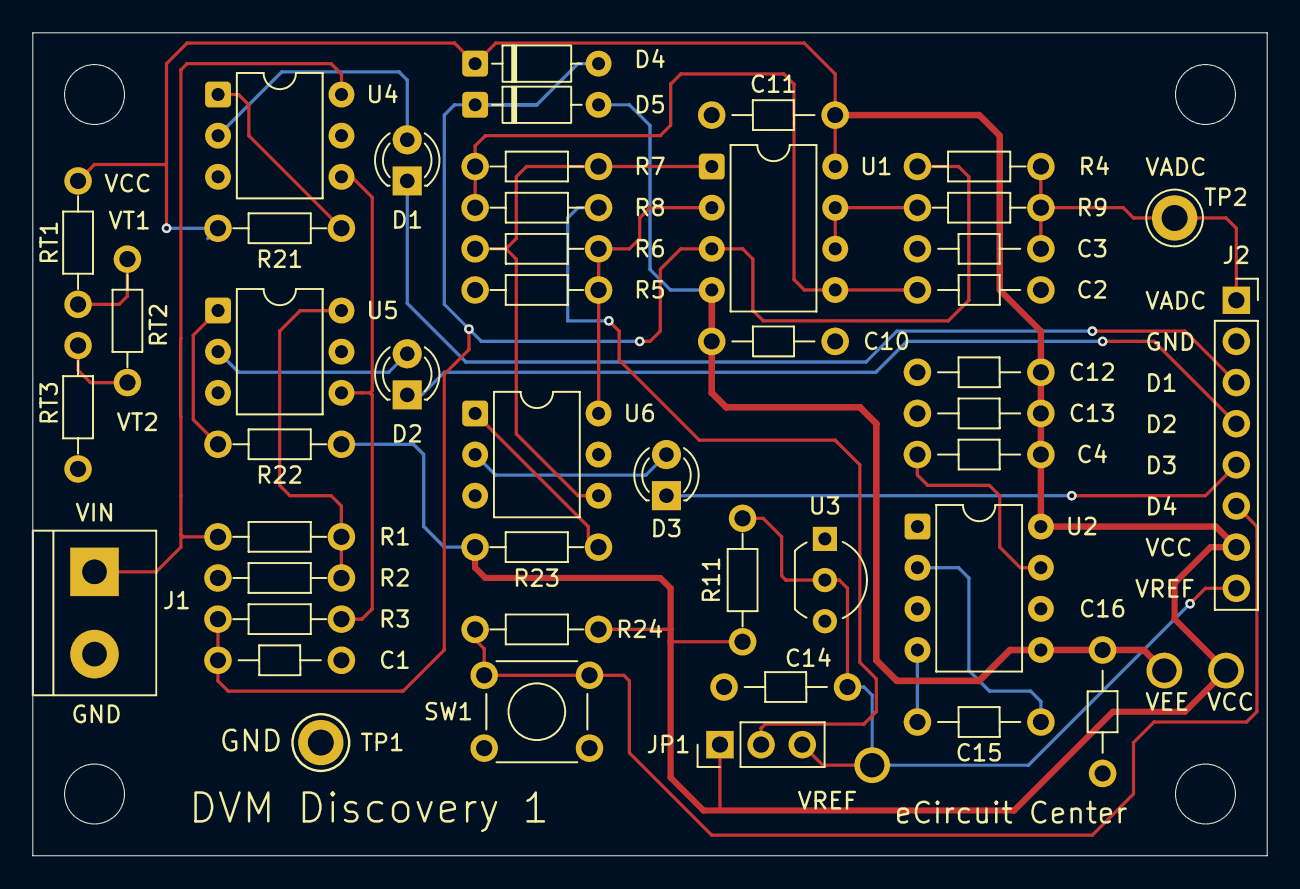
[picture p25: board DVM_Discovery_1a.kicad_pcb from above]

Board: 2 copper layers, 76.2 x 50.8 mm, 52 parts (0 on the bottom side), 29 nets.

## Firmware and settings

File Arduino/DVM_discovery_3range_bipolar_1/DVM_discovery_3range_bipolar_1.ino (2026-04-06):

/*
  DVM1 3-Range Bipolar Input

  Read ADC and convert to voltage at input.
  Display Vinput at PC screen
  Change Vrange on Button press
*/

int Vrange = 0;     // 0 - 4V Range, 1 - 20V Range
int ADCword = 0;    // ADC value (counts)
float Vinput = 0;   // input voltage (V)
float Vref = 5.0;   // reference voltage

char strRange[20];  // range name

// Rdivider
float R1 = 825000;         
float R2 = 200000;            

// Amplifier
float R5 = 10000;
float R6 = 30100;      

// Scale and Shift network
float R7 = 10000;
float R8 = 10000;
float Kscale = R8/(R7+R8);
float Vshift = Vref*R7/(R7+R8);

// Gain
float Kdiv = 1;
float Kamp = 1;
float Ktot = 1;

// switch control
const int SW1 = 11;           // sw1 control
const int SW2 = 12;           // sw2 control
const int SW3 = 13;           // sw2 control
const int buttonPin = 4;     // pushbutton input

// pushbutton press
int buttonState = 1;        // current state of the button
int lastButtonState = 1;    // previous state of the button

// the setup routine runs once *****************************
void setup() { 
  // initialize serial communication at 9600 bits per second:
  Serial.begin(9600);

  // configure digital pins
  pinMode(SW1, OUTPUT);               // set as output
  pinMode(SW2, OUTPUT);               // set as output
  pinMode(SW3, OUTPUT);               // set as output
  pinMode(buttonPin, INPUT_PULLUP);   // set as input

  // default standard range (no gains)
  Vrange = 0;   

  // divider direct in
  digitalWrite(SW1, LOW);   // sw1 ON
  digitalWrite(SW2, HIGH);  // sw2 OFF
  // Amplifier unity gain
  digitalWrite(SW3, LOW);  // sw3 ON

}



// the loop routine runs continuously **********************
void loop() {

  // read analog input from ADC at pin A0
  ADCword = analogRead(A0);
  
  // calc scale and shift
  float Kscale = R8/(R7+R8);
  float Vshift = Vref*R7/(R7+R8);

  // calc total scaling
  if (Vrange == 0) {  // Standard
    Kdiv = 1;
    Kamp = 1;
    Ktot = Kdiv * Kamp * Kscale;
  }
  else if (Vrange == 1) {  // High Range
    Kdiv = R2/(R1+R2);
    Kamp = 1;
    Ktot = Kdiv * Kamp * Kscale;
  }
  else if (Vrange == 2) {  // Lo Range
    Kdiv = 1;
    Kamp = (R6/R5+1);
    Ktot = Kdiv * Kamp * Kscale;   
  }

  // convert ADC counts to input voltage
  // Vinput = ADCvalue * Vref/2^N * 1/Kdiv
  Vref = 5.0;
  Vinput = (ADCword*(Vref/1024) - Vshift)*1/(Ktot);

  // read Vrange Pushbutton 
  buttonState = digitalRead(buttonPin);
  
  // check for Hi to Lo transition
  if (lastButtonState == 1 && buttonState == 0) {
 
    // if transition, then increment voltage range
    Vrange++;

    // reset to 0 if need
    if (Vrange > 2) {
      Vrange = 0; 
    }
 
  }

  // update last state
  lastButtonState = buttonState;
  
    // set Vrange switches at R Divider and Amp
  if (Vrange == 0) { // Standard Range
    // sw to straight in
    digitalWrite(SW1, LOW);   // sw1 ON
    digitalWrite(SW2, HIGH);  // sw2 OFF
    // Amplifier unity gain
    digitalWrite(SW3, LOW);  // sw3 ON
    // name range
    sprintf(strRange, "4V Range");
  }

  if (Vrange == 1) { // High Voltage
    // sw to divider tap
    digitalWrite(SW1, HIGH);  // sw1 OFF
    digitalWrite(SW2, LOW);   // sw2 ON
    // Amplifier unity gain
    digitalWrite(SW3, LOW);  // sw2 ON
    // name range
    sprintf(strRange, "20V Range");
  }

  if (Vrange == 2) {  // Low Voltage
    // sw to straight in
    digitalWrite(SW1, LOW);   // sw1 ON
    digitalWrite(SW2, HIGH);  // sw2 OFF
    // Amplifier Gain
    digitalWrite(SW3, HIGH);  // sw3 OFF
    // name range
    sprintf(strRange, "1V Range");
  }

  // time delay (ms) for approx 4 readings per second
  delay(250); 

  // print out the values to computer as ASCII
 
  Serial.print("Vinput,ADCword,buttonState,Vrange,strRange:\t");
  if(ADCword > (1023 - 51)){     // check overange 95% to max
        Serial.print("OverRng");
  }
  else if (ADCword < 51){  // check under range 5% of max
        Serial.print("UnderRng");
  }
  else {
        Serial.print(Vinput,3);
  }
  Serial.print("\t"); 
  Serial.print(ADCword);
  Serial.print("\t"); 
  Serial.print(buttonState);
  Serial.print("\t"); 
  Serial.print(Vrange);
  Serial.print("\t");
  Serial.println(strRange);
}

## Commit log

2026-04-06 add user guide, kicad files
    [DVM_Discovery_1a.kicad_pcb, DVM_Discovery_1a.kicad_sch, dvm-discovery-calculator-1a.xlsx]
2026-04-06 add Arduino code
